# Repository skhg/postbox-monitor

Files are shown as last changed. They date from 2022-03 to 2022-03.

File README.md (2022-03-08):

# postbox-monitor
I don't like checking my postbox every day for new deliveries, so I built a monitoring system that notifies me by email when something arrives. It works!

## The finished product
Here's how it looks, when installed:

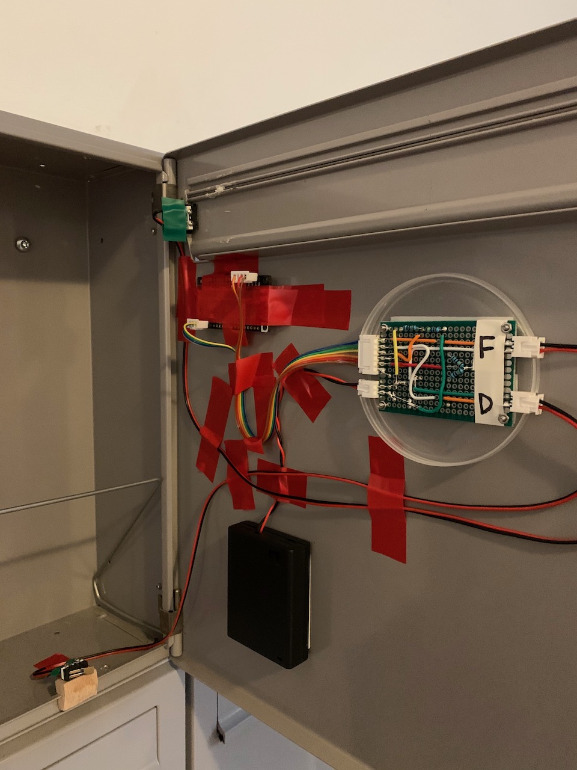
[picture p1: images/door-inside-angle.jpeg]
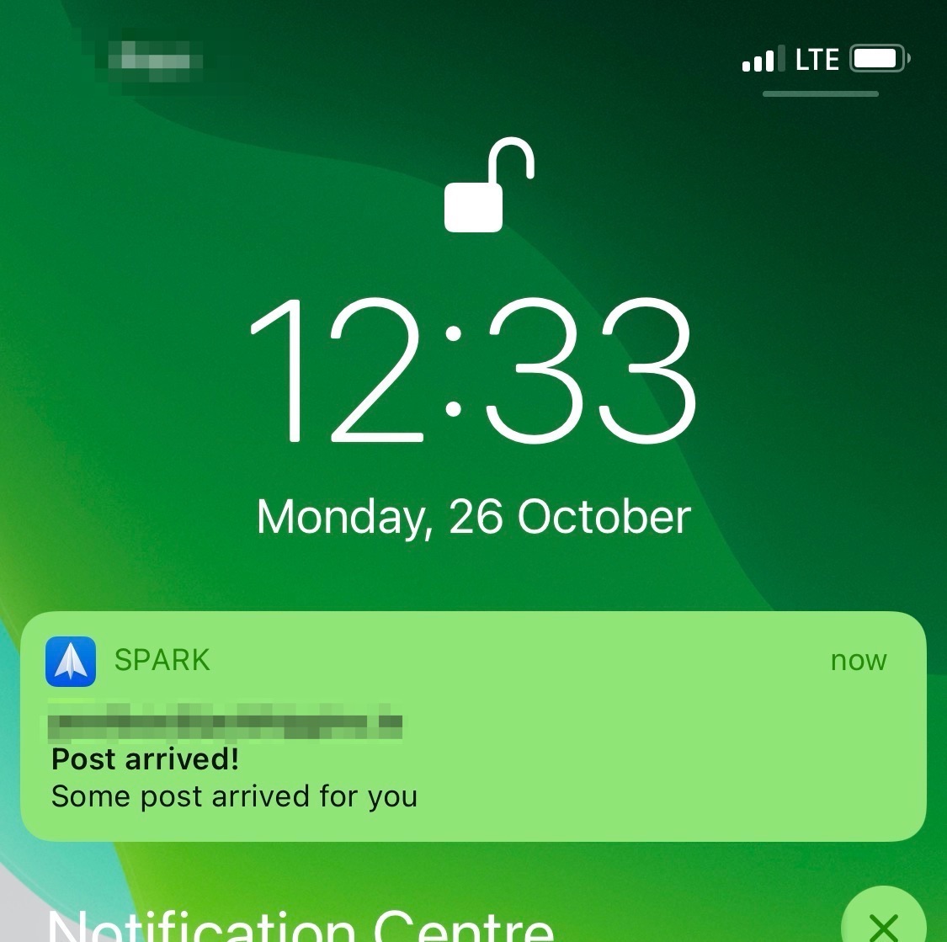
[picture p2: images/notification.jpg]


(and what the notification looks like!)

That's a battery pack, main bus board, microcontroller board, and two switches, all stuck on the inside of my postbox door. It looks like a mess, but the important thing is to ensure nothing falling into the postbox can dislodge any cables or connectors accidentally.

## Goals for the project
 * Be **virtually invisible** from outside the postbox
 * Run on battery power for at least ~1 year without discharging
 * Break "rarely"
 * "Very low" false positive rate 
 * Be resiliant to WiFi outages or failure

## Materials required
Electronics:
* 4x AAA [battery pack](https://www.amazon.de/-/en/gp/product/B077P186ZN/ref=ppx_yo_dt_b_search_asin_title?ie=UTF8&psc=1) 
* Various cables
* Perfboard
* JST connectors
* 1x [FireBeetle ESP32 microcontroller](https://www.amazon.de/-/en/gp/product/B075CV6GR4/ref=ppx_yo_dt_b_search_asin_title?ie=UTF8&psc=1)
* 2x [Micro switches](https://www.amazon.de/gp/product/B07YDFH7H3/ref=ppx_yo_dt_b_asin_title_o02_s01?ie=UTF8&psc=1)

Other:
* Little blocks of wood
* Thin pieces of rubber
* Lots of insulating tape
* Small screws

Other systems:
* Since this device can't send email by itself, you'll need something which can host the REST endpoints that this board will connect to, when events occur. More on that later 

## Design, build & test
My postbox is a sealed metal box, one of a bank of other postboxes installed in a public hallway in my building. This severely constrains the options for remote monitoring.
* Solid metal means WiFi can't penetrate.
* No external power supply is possible.
* No interference with my neighbours postboxes is allowed.
* Nothing can be mounted on the outside, so as not to attract attention.

On the first point however there is a tiny exception - the only gap in the metal box is a slot for a plastic name tag, just a few cm wide. But it's big enough to let a signal through!

So next consideration is how to make this as low-maintenance as possible. Just do the absolute minimum, use as little power as possible, and keep operating even if external systems go offline.

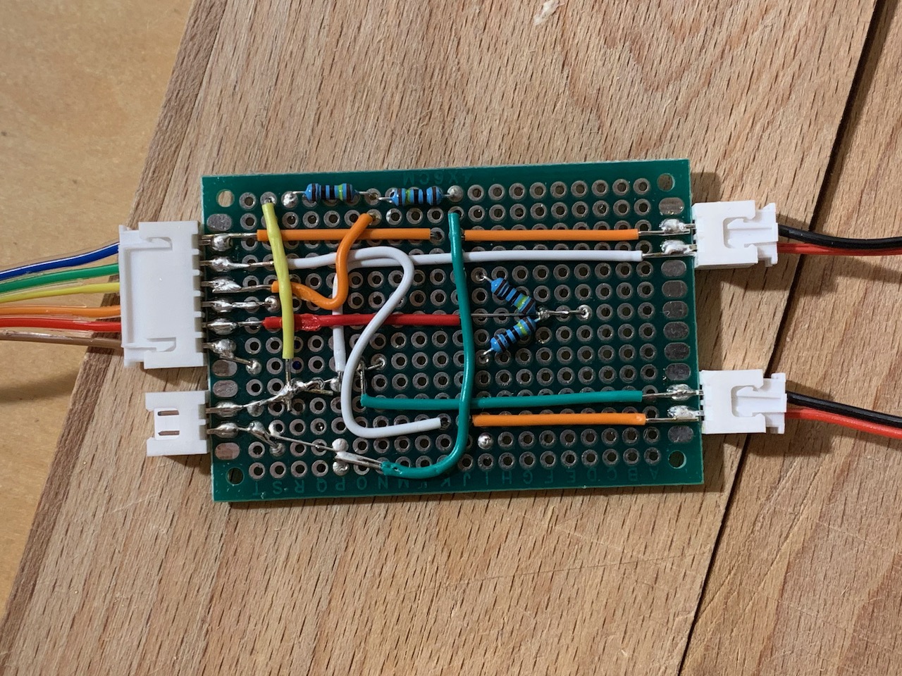
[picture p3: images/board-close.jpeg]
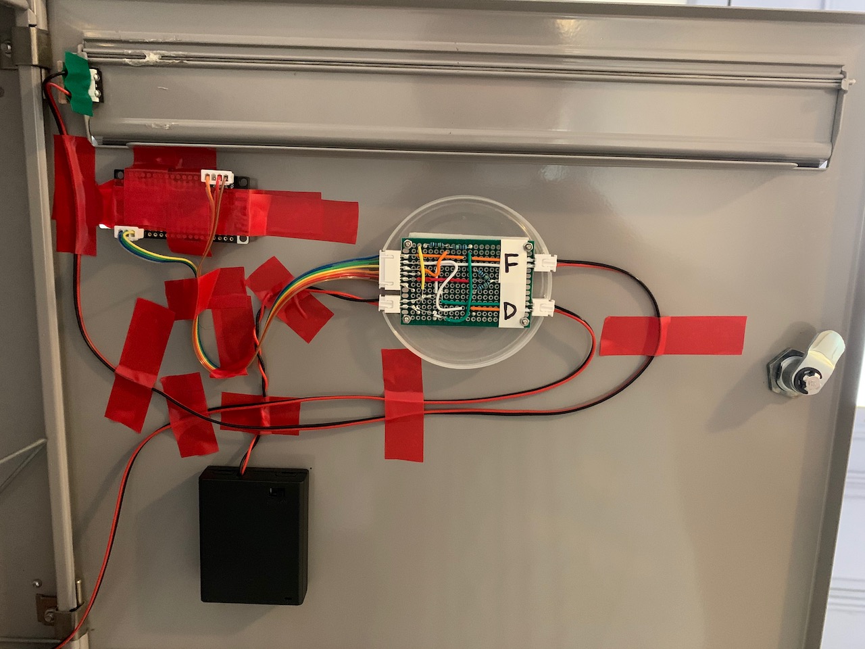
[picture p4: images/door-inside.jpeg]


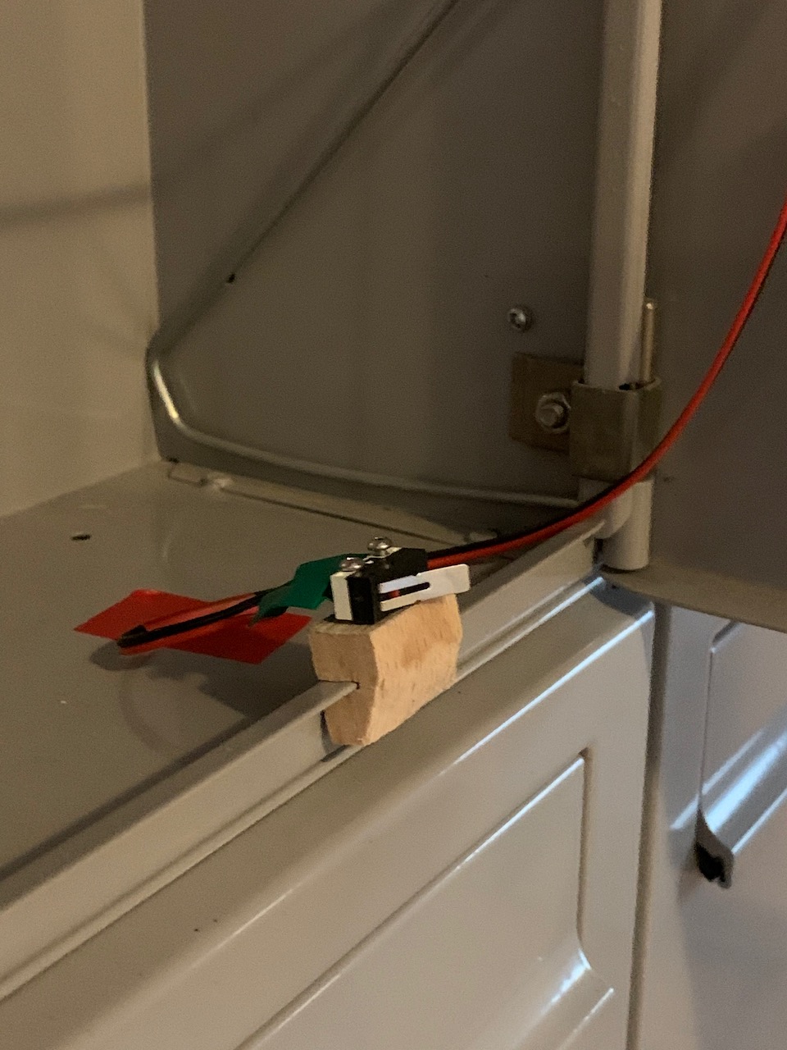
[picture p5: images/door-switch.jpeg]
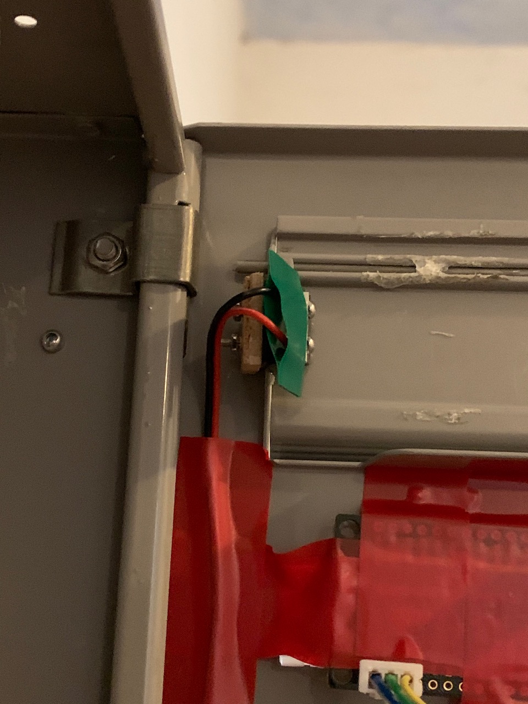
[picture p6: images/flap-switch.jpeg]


### Extreme power efficiency
I chose the [FireBeetle ESP32](https://www.dfrobot.com/product-1590.html) board due to its extreme power efficiency. It supports a deep sleep mode that consumes just 10μA, with no board modifications required! Before sleeping, a number of trigger pins can be set. One can wake the board when the flap opens, and another when the door opens.

### Resilient WiFi connectivity
The WiFi network from my apartment upstairs might not always be available, due to various factors. So it's important the board can make a best effort to connect, but not waste time if the network or endpoint is unavailable at that moment.

I use a simple fibonacci backoff strategy which increases the time interval between subsequent retries, up to a maximum of 24 hours. Every 24 hours the system pings home to report it's still alive, so there is no need to exceed this limit.

### Circuit diagram
Here's a general overview:
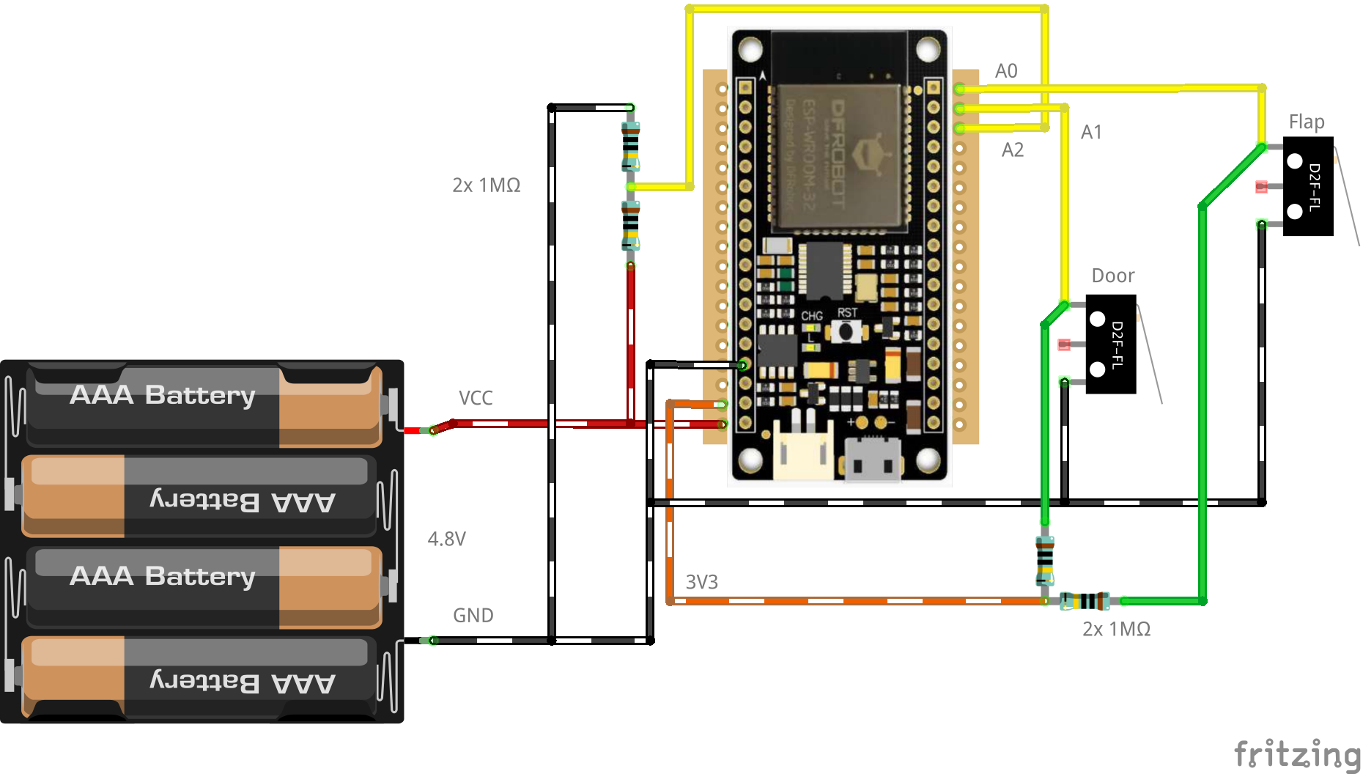
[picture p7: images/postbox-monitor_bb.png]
Circuit overview

<i>(Exported from Fritzing [file](images/postbox-monitor.fzz))</i>

### Workflow
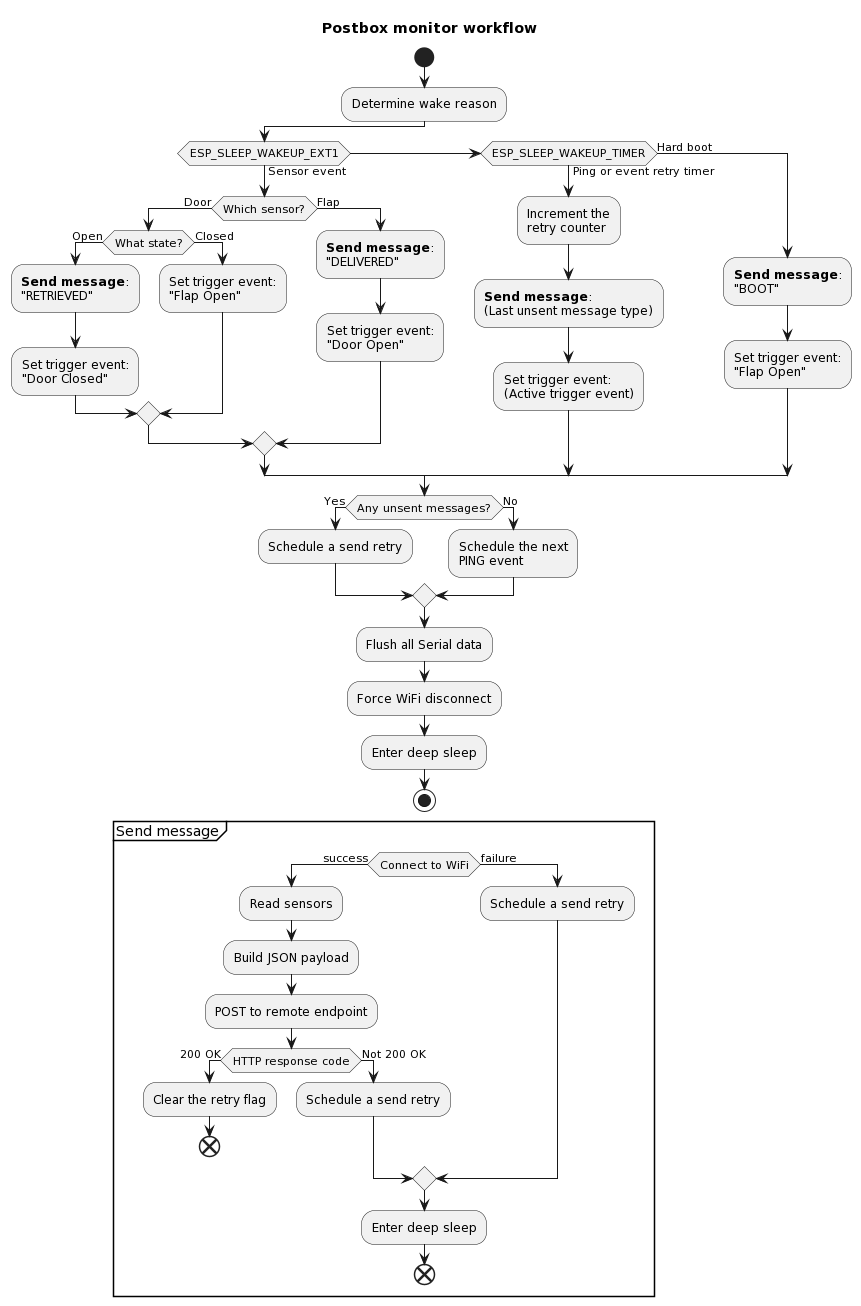
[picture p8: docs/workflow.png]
Workflow

<i>(Exported from `.puml` [file](docs/workflow.puml))</i>

## Installation
Here's how it was designed for installation with a bus board:
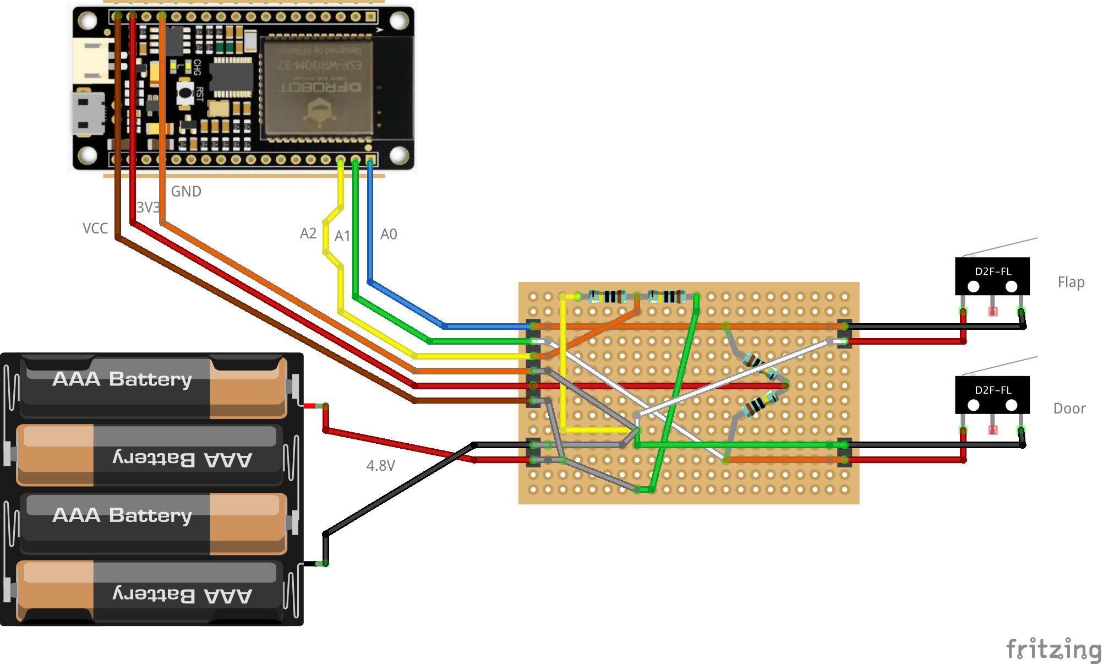
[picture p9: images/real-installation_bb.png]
Installation diagram

<i>(Exported from Fritzing [file](images/real-installation.fzz))</i>

## Event handling and monitoring
I run a Spring Boot service which hosts several controllers for capturing domestic data (e.g. my [weather station](https://github.com/skhg/weather-station)). This also includes two endpoints for capturing events from the postbox:

`POST /postbox/boot`

`POST /postbox/delivered`

`POST /postbox/retrieved`

`POST /postbox/ping`

Each call also supplies a very minimal JSON blob, for example:

```json
{
  "deviceVoltageMeasurement": 1234,
  "retryCount": 5
}
```

When my service handles a `/delivered` or `/retrieved` request, I either send a new email notifying that post has arrived, or clear the message. The details of how that's done are outside the scope of this project.  

With the additional device data I recieve in the JSON contents, I can conveniently monitor the power voltage (in mV) and the condition of the WiFi connection over time.

## Performance analysis
My service pushes all event data to InfluxDB for later analysis using Grafana. After a few hiccups at the start the system completed its "commissioning" on 2020-10-25. Its first set of batteries lasted until 2022-03-02 when their voltage dropped below the required 3.3V.

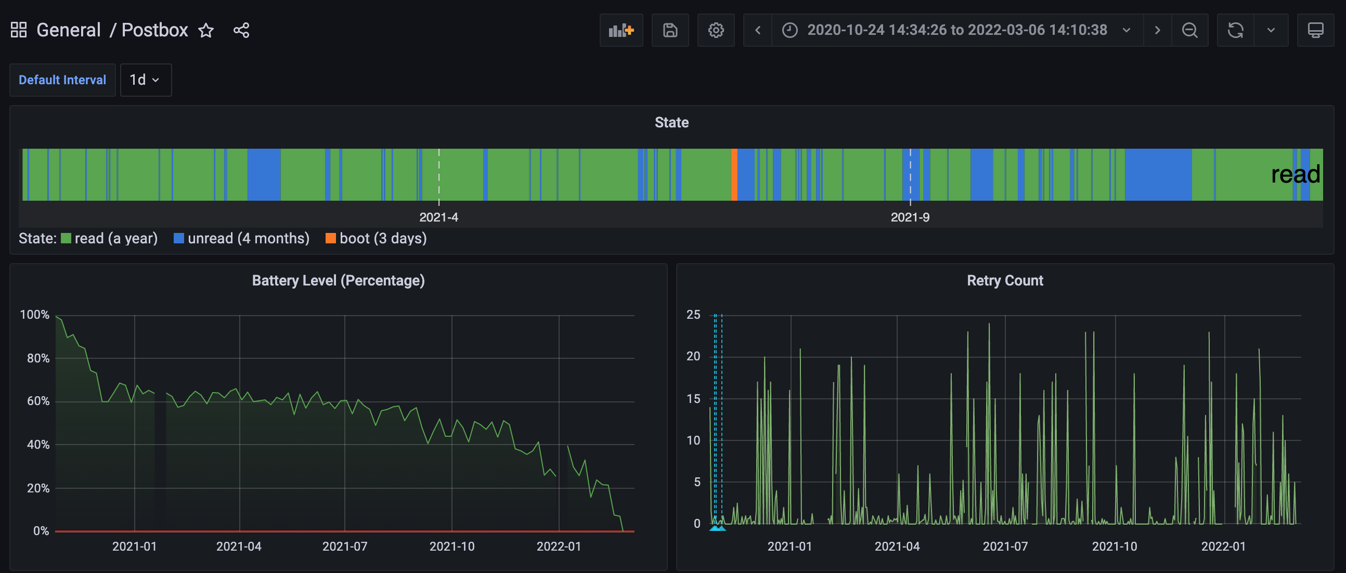
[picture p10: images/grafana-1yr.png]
Grafana dashboard


_Note: I'm using the [Discrete](https://grafana.com/grafana/plugins/natel-discrete-panel/) panel Grafana plugin to show the postbox state over time. Green: "read", blue: "unread", orange: "booted"._

### Power consumption
With the [batteries](https://www.amazon.de/-/en/gp/product/B007B9NXAC/ref=ppx_yo_dt_b_search_asin_title?ie=UTF8&psc=1) claiming a capacity of 800mAh, this means the system is consuming [an average](https://www.omnicalculator.com/other/battery-life) of 68µA over ~12,000 hours (493 days).

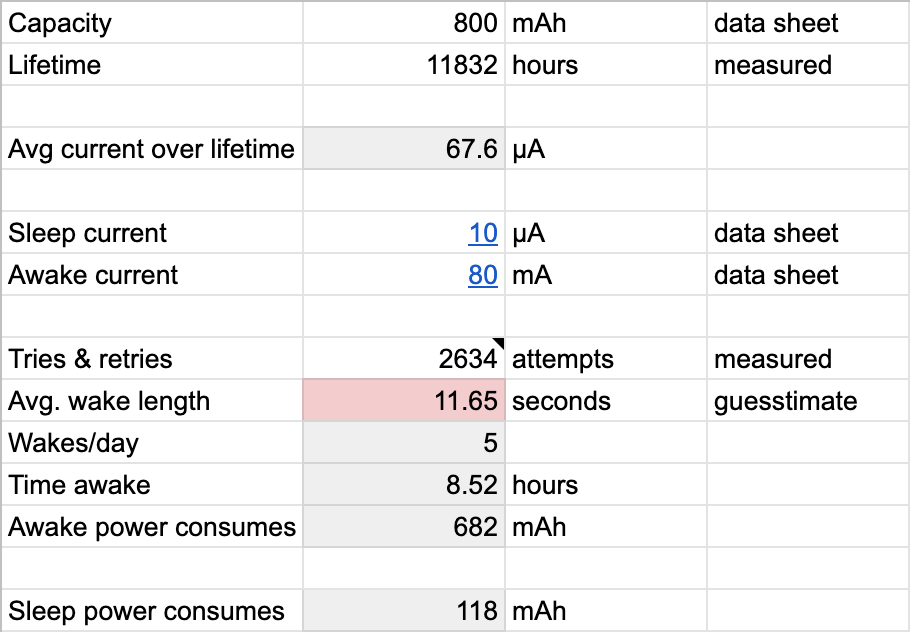
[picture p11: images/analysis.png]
Analysis Analysis sheet

<i>Generated from <a href="https://docs.google.com/spreadsheets/d/1rllKjjHKtWIUKkeni1poOeJL0zPl1OUqKPO-2vArXlA/edit?usp=sharing">this sheet</a></i>

Including retries, Influx recorded 2634 "attempts" to connect and report data during ths period. Out of the 839 events (pings, deliveries and retrievals) during this period, 302 (about 36%) required a connection retry.

I'm not really sure how much power is consumed by the board while WiFi is active. The data sheet reports "typical" power consumption of 80mA when awake. Based on this, and considering how many attempts total were made during the period, it looks like the board was awake for a total of around 8.5 hours.

The 11.65 seconds average wake time _might_ be largely defined by the 10 seconds `WIFI_CONNECT_TIMEOUT_SECONDS` value. A useful measurement to follow up with, would be to see how long it typically takes to make a successful connection, and reduce this value. If no connections ever succeed after (for example) 5 seconds, then there is no point in waiting 10 seconds.

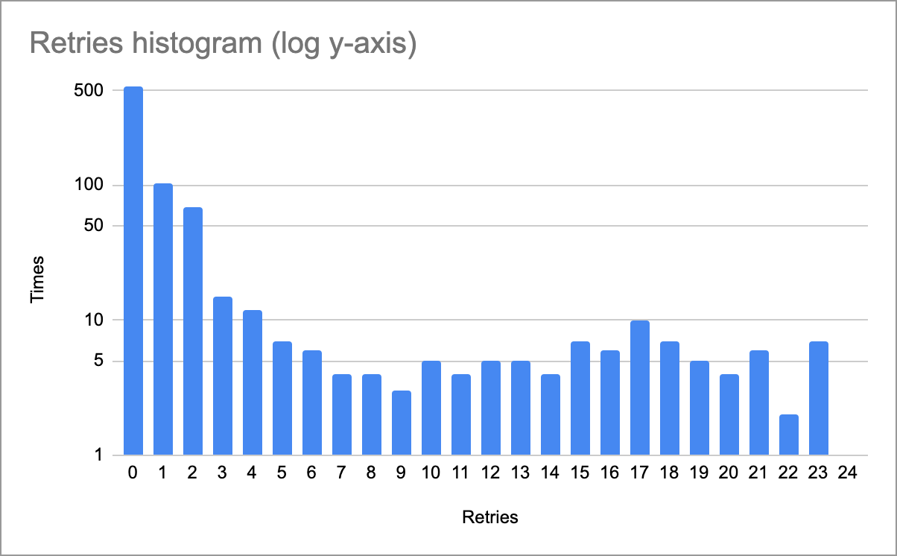
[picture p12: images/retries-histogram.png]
Retry chart Retries chart

<i>Generated from <a href="https://docs.google.com/spreadsheets/d/1rllKjjHKtWIUKkeni1poOeJL0zPl1OUqKPO-2vArXlA/edit?usp=sharing">this sheet</a></i>

Retry success seems to get a bit worse around the 9th retry (approx delay of 3 minutes), and improve again at the 17th retry (approx delay of 72 minutes). I have no idea why this happens yet.

### Peak hours
I can also see what were the peak hours of activity during the year. No surprises here: Deliveries usually happen in the morning, peaking around 10-11am. A few hours later, I collect the post. Both tail off in the evening, and not much happens between 8pm - 7am.

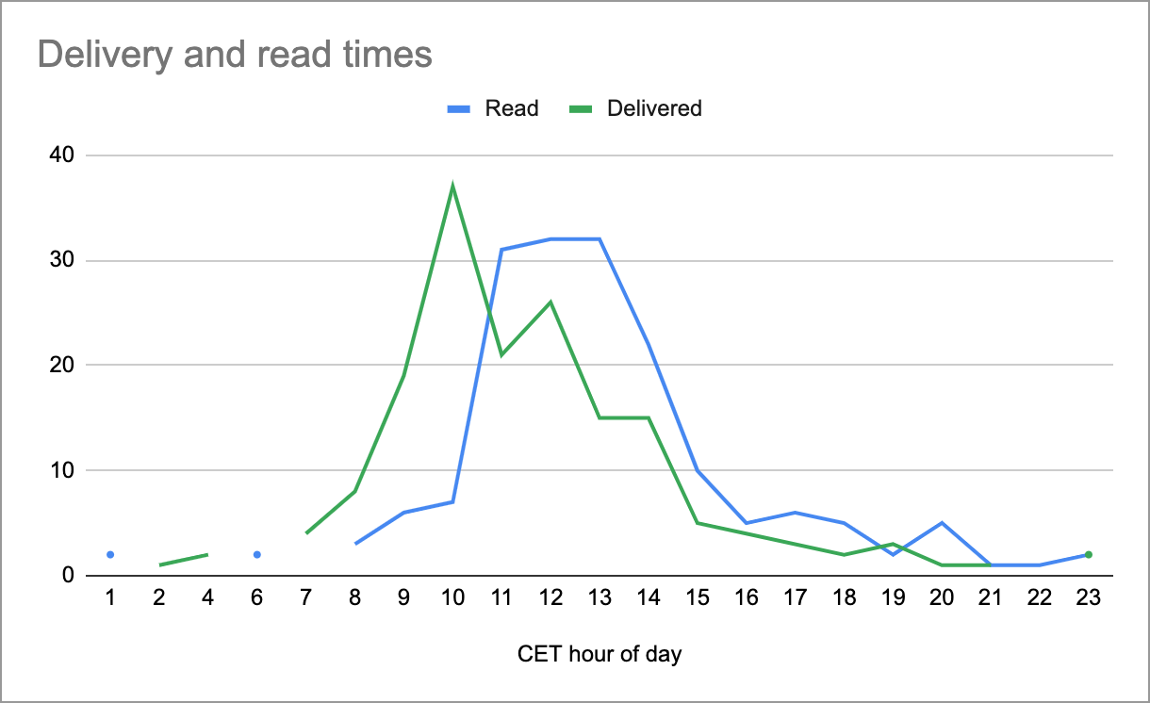
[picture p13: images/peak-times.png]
Peak hours Peak times

<i>Generated from <a href="https://docs.google.com/spreadsheets/d/1rllKjjHKtWIUKkeni1poOeJL0zPl1OUqKPO-2vArXlA/edit?usp=sharing">this sheet</a></i>

### Retries needed vs time of day
This chart does an analysis of the number of attempts needed to succeed in connecting to the network, for any event type. This is normalised for the number of events that happened during that hour.

Seems like the evenings are worse, mornings are better. More WiFi interference at busy hours of the evening, maybe? 

The good news however: since most deliveries happen in the morning, those events will get through within a few seconds, on average. 

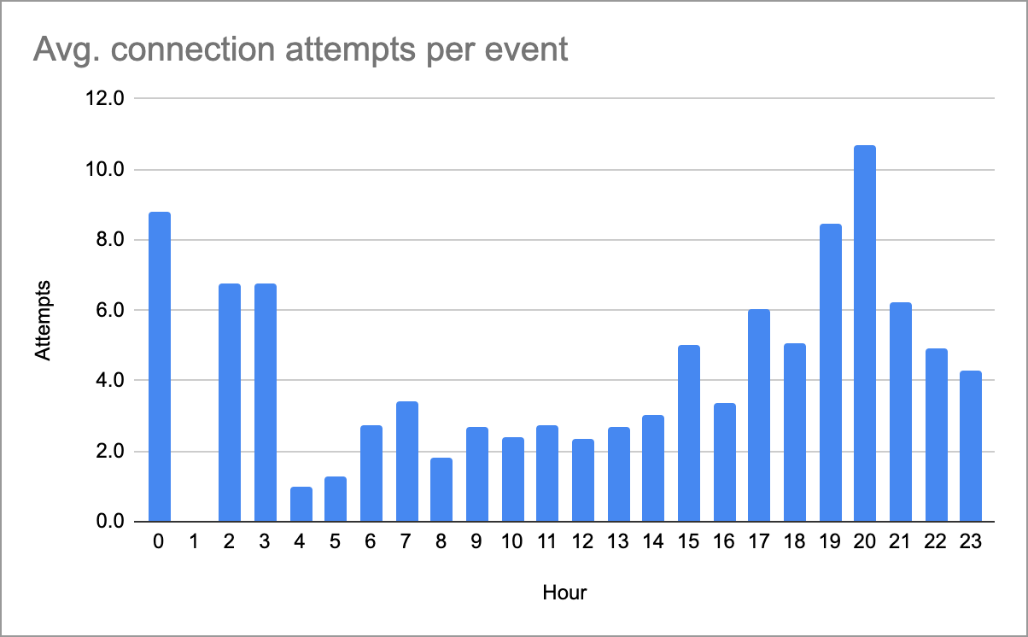
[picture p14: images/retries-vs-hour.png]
Connection efforts needed Retries vs hour

<i>Generated from <a href="https://docs.google.com/spreadsheets/d/1rllKjjHKtWIUKkeni1poOeJL0zPl1OUqKPO-2vArXlA/edit?usp=sharing">this sheet</a>. Note: Very few events between 1am to 4am so those numbers might be safe to ignore.</i>

## Ideas for improvement

Reduce the number of retries, which would further reduce power required
*  I don't really know why the retry count varies so much over time. It might be due to interference, temperature, WiFi network activity, etc. 

Built-in camera
* A camera, mounted to the interior, could take a photo when new post arrives (with a brief LED flash to illuminate). This would be sent with the email alert

Slimmer mounting on the postbox door
* With a bit more finesse the wires & connectors could be made to protrude less from the microcontroller board - this would reduce the risk of a big parcel disconnecting some wires. (This happened at least once already)

Simplify the workflow
* After review it seems there are some possible problems with the code, in that events might not be detected, if a previous event has not yet been sent. This probably deserves another look.

Email send retry
* If the REST endpoint is accessible but the internet isn't, the notification email will not be sent. I need to add a retry mechanism for the fairly unlikely event that the internet is down. This has happened at least twice over the past year.

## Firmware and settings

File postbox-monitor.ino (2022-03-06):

/**
 * Copyright 2022 Jack Higgins : https://github.com/skhg
 * All components of this project are licensed under the MIT License.
 * See the LICENSE file for details.
 */

/**
 * Network Configuration
 */
#define WIFI_CONNECT_TIMEOUT_SECONDS 10
#define SERVER_ROOT "http://192.168.178.29:8080/postbox"
#define WIFI_CLIENT_HOSTNAME "postbox"

/**
 * Ping interval in seconds
 */
#define PING_INTERVAL_SECONDS 86400  // 1 day = 86400 = 60 * 60 * 24









/**
 * Http defaults which never change
 */

#define HTTP_OK 200
#define HTTP_CONTENT_TYPE_HEADER "Content-Type"
#define HTTP_CONTENT_LENGTH_HEADER "Content-Length"
#define HTTP_APPLICATION_JSON_CONTENT_TYPE "application/json"

/**
 * Data points required for voltage measurement
 */
#define STABILISING_DATA_POINTS 100
#define STABILISING_POINT_INTERVAL 10

/**
 * Pin Mappings and hardware configuration
 */

#define FLAP_BUTTON_MASK 0x1000000000  // Button connected to GPIO36 (A0)
#define DOOR_BUTTON_MASK 0x8000000000  // Button connected to GPIO39 (A1)
#define uS_TO_S_FACTOR 1000000ULL  // Conversion from microseconds to seconds
#define FLAP A0
#define DOOR A1
#define VOLTAGE_PIN A2








/**
 * States and event types
 */
enum DOOR_STATES {
  OPEN,
  CLOSED
};

enum NOTIFY_TYPES {
  NO_EVENT,
  BOOT,
  DELIVERED,
  RETRIEVED,
  PING
};







/**
 * Variables which are persistent during deep sleep
 */
RTC_DATA_ATTR long _retryCount = 0;
RTC_DATA_ATTR int _triggerSwitch = DOOR;
RTC_DATA_ATTR int _waitingForState = CLOSED;
RTC_DATA_ATTR NOTIFY_TYPES _pendingTransmission = NO_EVENT;








#include <home_wifi.h>
#include <WiFi.h>
#include <HTTPClient.h>
#include <ArduinoJson.h>

WiFiClient WIFI_CLIENT;
HTTPClient HTTP_CLIENT;

void setup() {
  Serial.begin(115200);

  switch (esp_sleep_get_wakeup_cause()) {
    case ESP_SLEEP_WAKEUP_EXT1: {
      Serial.println("Woke due to sensor event");
      onSensorWake();
      break;
    }
    case ESP_SLEEP_WAKEUP_TIMER: {
      Serial.println("Woke due to timer event");
      onTimerWake();
      break;
    }
    default: {
      Serial.println("Woke due to boot event");
      onBootWake();
      break;
    }
  }

  scheduleNextPing();

  Serial.flush();
  WiFi.disconnect();

  esp_deep_sleep_start();
}

void loop() { }

void onTimerWake() {
  executeSchedule();
  waitFor(_triggerSwitch, _waitingForState);
}

void onBootWake() {
  _retryCount = 0;
  notify(BOOT);
  waitFor(FLAP, OPEN);
}

void onSensorWake() {
  _retryCount = 0;
  switch (_triggerSwitch) {
    case FLAP: flapOpened(); break;
    case DOOR: doorOpened(); break;
  }
}

void executeSchedule() {
  if (_pendingTransmission != NO_EVENT) {
    _retryCount++;
    notify(_pendingTransmission);
  }
}

void scheduleNextPing() {
  if (_pendingTransmission != NO_EVENT) {
    Serial.print("Not scheduling a ping because a ");
    Serial.print(notifyTypeToString(_pendingTransmission));
    Serial.println(" transmission is already pending.");
    scheduleRetry(_pendingTransmission);
    return;
  }

  _pendingTransmission = PING;
  _retryCount = -1;

  Serial.print("Scheduling next ping for ");
  Serial.print(PING_INTERVAL_SECONDS);
  Serial.println(" seconds from now...");

  uint64_t microsecondsToGo = PING_INTERVAL_SECONDS * uS_TO_S_FACTOR;
  esp_sleep_enable_timer_wakeup(microsecondsToGo);
}

void scheduleRetry(NOTIFY_TYPES notifyType) {
  Serial.println("Retry scheduled");
  _pendingTransmission = notifyType;

  long t1 = 0;
  long t2 = 1;
  long nth = 1;

  for (long i = 2; i <= _retryCount; i++) {
    nth = t1 + t2;
    t1 = t2;
    t2 = nth;

    if (nth >= PING_INTERVAL_SECONDS) {
      break;
    }
  }

  Serial.print("Scheduling retry for ");
  Serial.print(nth);
  Serial.println(" seconds from now...");

  uint64_t delayTimeMicroseconds = nth * uS_TO_S_FACTOR;

  esp_sleep_enable_timer_wakeup(delayTimeMicroseconds);
}

void clearRetry() {
  _pendingTransmission = NO_EVENT;
  _retryCount = 0;
}

String buildMessage() {
  DynamicJsonDocument json(JSON_OBJECT_SIZE(2));

  json["deviceVoltageMeasurement"] = voltageReading();
  json["retryCount"] = _retryCount;

  String serialised;
  serializeJson(json, serialised);

  return serialised;
}

void notify(NOTIFY_TYPES notifyType) {
  if (!connectToWifi()) {
    scheduleRetry(notifyType);
    return;
  }

  String path;

  switch (notifyType) {
    case NO_EVENT: return;
    case BOOT: path = "/boot"; break;
    case DELIVERED: path = "/delivered"; break;
    case RETRIEVED: path = "/retrieved"; break;
    case PING: path = "/ping"; break;
    default: return;
  }

  String jsonString = buildMessage();

  Serial.print("Posting ");
  Serial.print(jsonString);
  Serial.print(" to ");
  Serial.println(path);

  HTTP_CLIENT.begin(WIFI_CLIENT, String(SERVER_ROOT) + path);
  HTTP_CLIENT.addHeader(HTTP_CONTENT_TYPE_HEADER, HTTP_APPLICATION_JSON_CONTENT_TYPE);
  HTTP_CLIENT.addHeader(HTTP_CONTENT_LENGTH_HEADER, String(jsonString.length()));
  int result = HTTP_CLIENT.POST(jsonString);

  if (result == HTTP_OK) {
    Serial.println("HTTP POST completed successfully!");
    clearRetry();
  } else {
    Serial.print("HTTP POST failed with code "); Serial.println(result);
    scheduleRetry(notifyType);
  }
}

void flapOpened() {
  Serial.println("Post arrived!");
  notify(DELIVERED);
  waitFor(DOOR, OPEN);
}

void doorOpened() {
  switch (_waitingForState) {
    case OPEN: {
      Serial.println("Door opened!");
      notify(RETRIEVED);
      waitFor(DOOR, CLOSED);
      break;
    } case CLOSED: {
      Serial.println("Door closed!");
      waitFor(FLAP, OPEN);
      break;
    }
  }
}

void waitFor(int switchName, int nextState) {
  Serial.print("Waiting for ");

  _triggerSwitch = switchName;
  _waitingForState = nextState;

  esp_sleep_ext1_wakeup_mode_t wakeMode;


  switch (nextState) {
    case OPEN: {
      wakeMode = ESP_EXT1_WAKEUP_ALL_LOW;
      Serial.print("opening");
      break;
    } case CLOSED: {
      wakeMode = ESP_EXT1_WAKEUP_ANY_HIGH;
      Serial.print("closing");
      break;
    }
  }

  Serial.print(" of ");

  switch (switchName) {
    case DOOR: {
      esp_sleep_enable_ext1_wakeup(DOOR_BUTTON_MASK, wakeMode);
      Serial.print("DOOR");
      break;
    }
    case FLAP: {
      esp_sleep_enable_ext1_wakeup(FLAP_BUTTON_MASK, wakeMode);
      Serial.print("FLAP");
      break;
    }
  }

  Serial.println(".");
}

int voltageReading() {
  pinMode(VOLTAGE_PIN, INPUT);

  int voltageValue = 0;
  for (int i=0; i < STABILISING_DATA_POINTS; i++) {
    voltageValue = voltageValue + analogRead(VOLTAGE_PIN);
    delay(STABILISING_POINT_INTERVAL);
  }

  voltageValue = voltageValue / STABILISING_DATA_POINTS;
  return voltageValue;
}

/**
 * Helper methods
 */

String notifyTypeToString(NOTIFY_TYPES notifyType) {
  switch (notifyType) {
    case NO_EVENT: return "no event";
    case BOOT: return "boot";
    case DELIVERED: return "delivered";
    case RETRIEVED: return "retrieved";
    case PING: return "ping";
    default: return "Unknown";
  }
}

/**
 * WiFi management
 */

boolean connectToWifi() {
  String wifiConnectionInfo = "Connecting to WiFi";


  if (WiFi.status() == WL_CONNECTED) {
    return true;
  }

  Serial.print("Connecting to ");
  Serial.println(WIFI_SSID);

  WiFi.setHostname(WIFI_CLIENT_HOSTNAME);
  WiFi.begin(WIFI_SSID, WIFI_PASSWORD);

  int connectAttempts = 0;
  int connectRetryInterval = 500;
  int failureCountdown = WIFI_CONNECT_TIMEOUT_SECONDS * 1000;

  while (WiFi.status() != WL_CONNECTED) {
    delay(connectRetryInterval);

    Serial.print(".");

    failureCountdown = failureCountdown - connectRetryInterval;

    if (failureCountdown < 0) {
      Serial.println("");
      Serial.println("Failed to connect.");
      return false;
    }
  }

  Serial.println("");
  Serial.println("WiFi connected");
  return true;
}

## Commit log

2019-01-27 add initial circuit diagram
    [postbox-monitor-diagram.fzz]
2019-01-28 basic sketch for postbox sensor, reed switches with power down
2019-01-29 checkin python sample code
2019-01-29 removed control terminal wires from diagram
    [postbox-monitor-diagram.fzz]
2019-01-29 read switches and send characters over bluetooth serial when activity detected
2019-02-06 update diagram with transistor
    [postbox-monitor-diagram.fzz]
2019-02-07 remove the unnecessary RX line
    [postbox-monitor-diagram.fzz]
2019-02-07 add power ctrl switch for bluetooth and rename method
2019-02-07 got consumption down to 19.4mA
2019-02-08 change position of tx and ctrl pins
    [postbox-monitor-diagram.fzz]
2019-02-09 add a simplified bluetooth sender for test purposes
    [postbox-monitor-diagram.fzz]
2019-03-10 circuit board diagram
    [circuit board.fzz]
2020-10-11 commit old work
    [postbox-monitor-diagram.fzz]
2022-01-16 Firebeetle (#1)
    * wip
    * handle retries and correct server address
    * use uint64_t for longer sleep times
    * fix bug in not correctly scheduling after door close event, and code cleanup
    [circuit board.fzz, postbox-board.fzz, postbox-monitor-diagram.fzz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]
2022-03-06 Docs and tidy (#4)
    * add lint/build workflow
    * add overall schematic
    * update diagrams
    * add photos and linter config
    * linting
    * move files
    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
    [postbox-board.fzz, postbox-monitor.fzz, real-installation.fzz]
